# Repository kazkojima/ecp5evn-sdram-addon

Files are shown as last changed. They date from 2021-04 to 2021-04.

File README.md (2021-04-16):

# KiCAD files of a SDR ram addon for ECP5 evaluation board

KiCAD files of a simple RAM addon for Lattice LEF5UM5G-85G

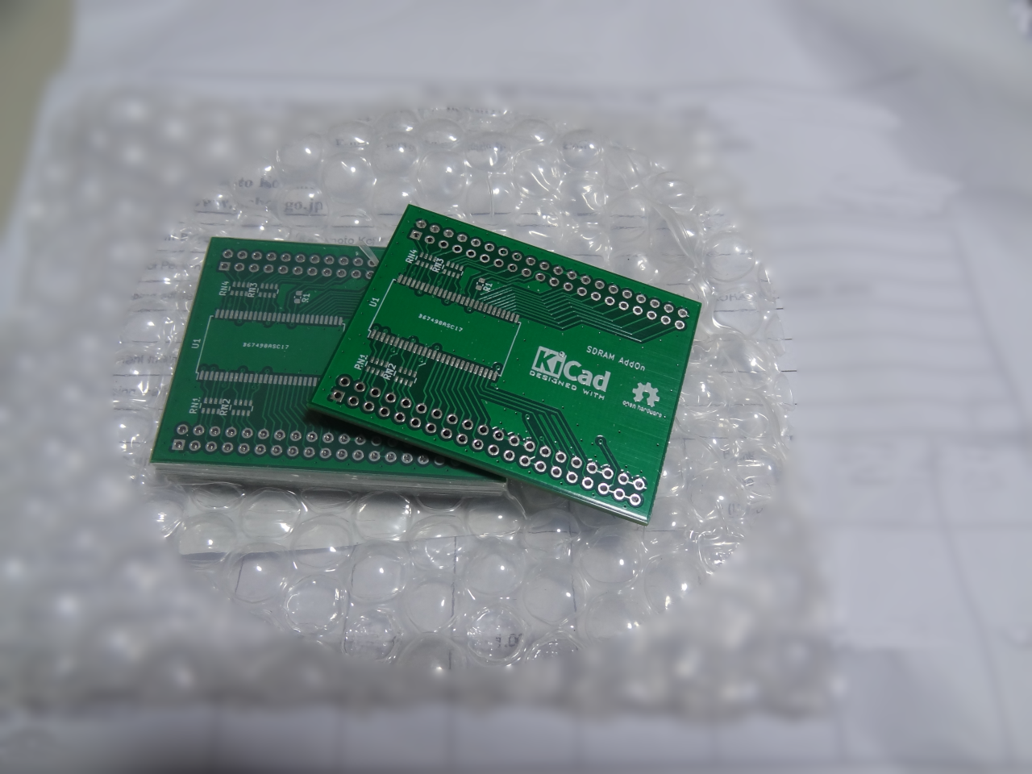
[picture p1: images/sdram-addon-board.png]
print board


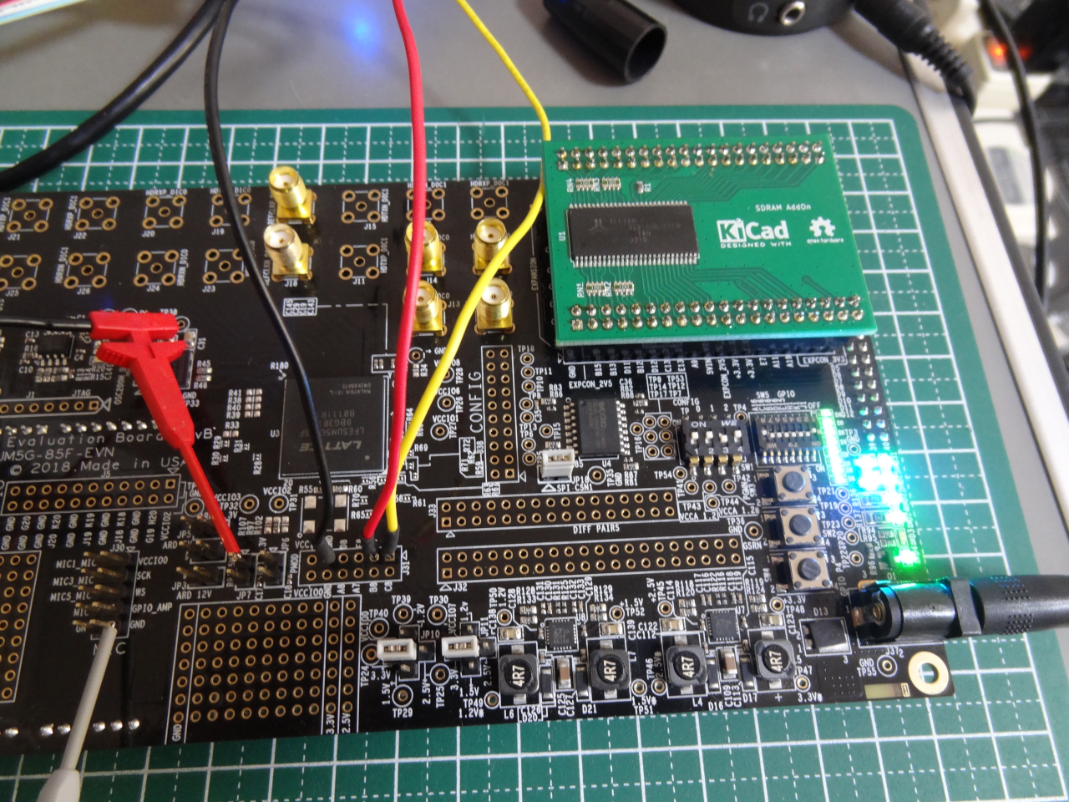
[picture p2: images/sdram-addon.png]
LEF5UM5G-85G+addon


## LiteX/[litex-boards](https://github.com/litex-hub/litex-boards.git) platform hunk of the addon

```
    # SDR SDRAM on connector J39 and J40
    ("sdram_clock", 0, Pins("K5"), IOStandard("LVCMOS33")),
    ("sdram", 0,
        Subsignal("a",     Pins(
            "B10 E7  A11 A19 K4  D14 P1  C14",
            "L1  L2  A9  N2  L3")),
        Subsignal("dq",    Pins(
            "D15 B15 C15 B13 B20 D11 E11 B12",
            "N4  M4  L4  J3  J4  H2  A15 K2")),
        Subsignal("we_n",  Pins("D12")),
        Subsignal("ras_n", Pins("C13")),
        Subsignal("cas_n", Pins("E12")),
        Subsignal("cs_n",  Pins("D13")),
        Subsignal("cke",   Pins("M5")),
        Subsignal("ba",    Pins("E13 A14")),
        Subsignal("dm",    Pins("C12 N3")),
        IOStandard("LVCMOS33"),
        Misc("SLEWRATE=FAST"),
    ),
```

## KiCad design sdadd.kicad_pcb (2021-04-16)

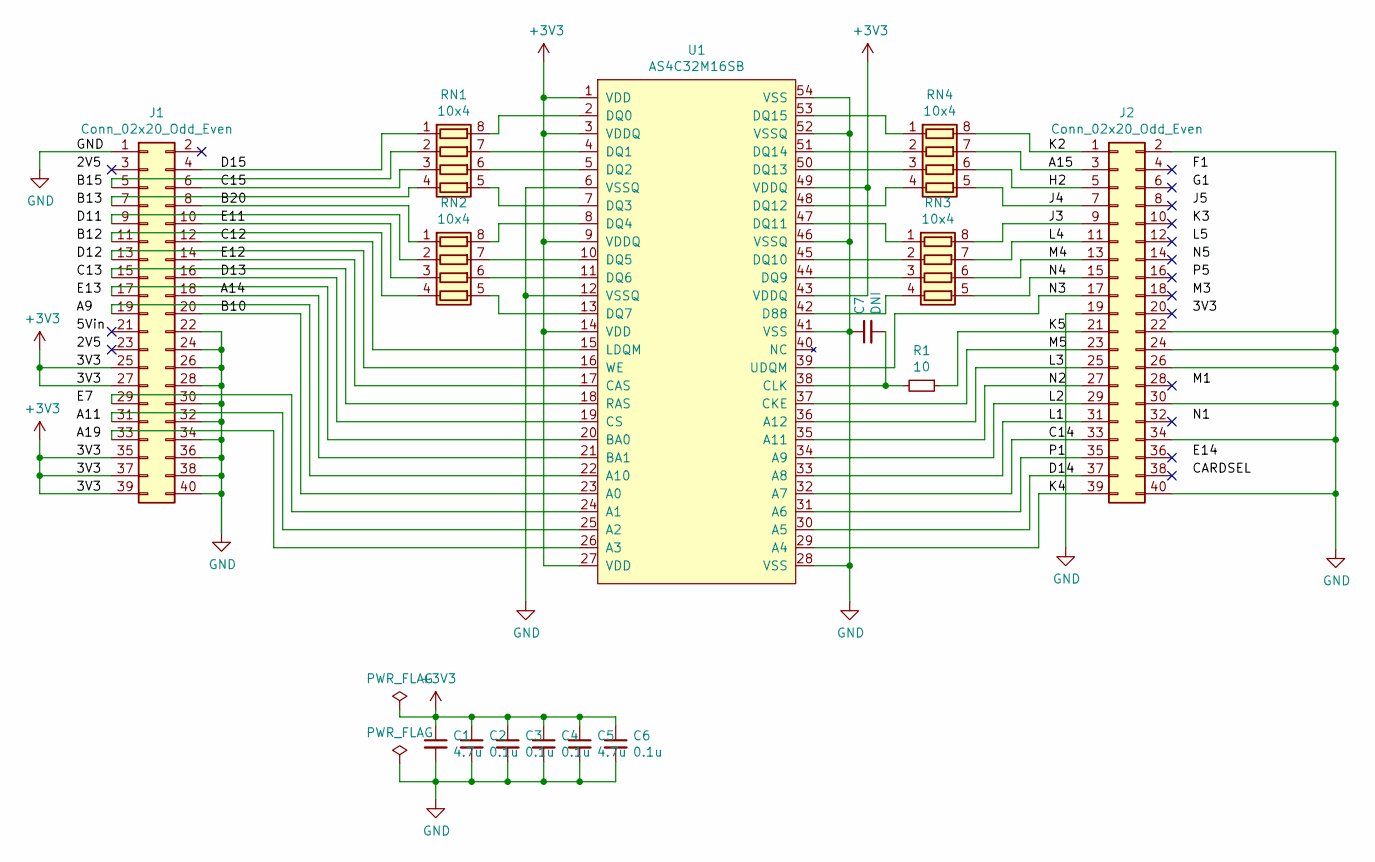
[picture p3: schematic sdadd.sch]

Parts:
C1, C5: 4.7u; C_0402_1005Metric
C2, C3, C4, C6: 0.1u; C_0402_1005Metric
C7: DNI; C_0402_1005Metric
J1, J2: Conn_02x20_Odd_Even; PinSocket_2x20_P2.54mm_Vertical
R1: 10; R_0603_1608Metric
RN1, RN2, RN3, RN4: 10x4; R_Array_Concave_4x0603
U1: AS4C32M16SB; TSOP-II-54_22.2x10.16mm_P0.8mm

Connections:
+3V3: C1.1, C2.1, C3.1, C4.1, C5.1, C6.1, J1.25, J1.27, J1.35, J1.37, J1.39, U1.1 (VDD), U1.3 (VDDQ), U1.9 (VDDQ), U1.14 (VDD), U1.27 (VDD), U1.43 (VDDQ), U1.49 (VDDQ)
/A14: J1.18, U1.21 (BA1)
/A15: J2.3, RN4.7 (R2.2)
/B10: J1.20, U1.23 (A0)
/B20: J1.8, RN2.1 (R1.1)
/C12: J1.12, U1.15 (LDQM)
/C14: J2.33, U1.32 (A7)
/C15: J1.6, RN1.3 (R3.1)
/D13: J1.16, U1.19 (CS)
/D14: J2.37, U1.30 (A5)
/D15: J1.4, RN1.1 (R1.1)
/E11: J1.10, RN2.3 (R3.1)
/E12: J1.14, U1.17 (CAS)
/H2: J2.5, RN4.6 (R3.2)
/J3: J2.9, RN3.8 (R1.2)
/J4: J2.7, RN4.5 (R4.2)
/K2: J2.1, RN4.8 (R1.2)
/K4: J2.39, U1.29 (A4)
/K5: J2.21, R1.1
/L1: J2.31, U1.33 (A8)
/L2: J2.29, U1.34 (A9)
/L3: J2.25, U1.36 (A12)
/L4: J2.11, RN3.7 (R2.2)
/M4: J2.13, RN3.6 (R3.2)
/M5: J2.23, U1.37 (CKE)
/N2: J2.27, U1.35 (A11)
/N3: J2.17, U1.39 (UDQM)
/N4: J2.15, RN3.5 (R4.2)
/P1: J2.35, U1.31 (A6)
GND: C1.2, C2.2, C3.2, C4.2, C5.2, C6.2, C7.1, J1.1, J1.22, J1.24, J1.26, J1.28, J1.30, J1.32, J1.34, J1.36, J1.38, J1.40, J2.2, J2.19, J2.22, J2.24, J2.26, J2.30, J2.34, J2.40, U1.6 (VSSQ), U1.12 (VSSQ), U1.28 (VSS), U1.41 (VSS), U1.46 (VSSQ), U1.52 (VSSQ), U1.54 (VSS)
unnamed: C7.2, R1.2, U1.38 (CLK)
unnamed: J1.5, RN1.2 (R2.1)
unnamed: J1.7, RN1.4 (R4.1)
unnamed: J1.9, RN2.2 (R2.1)
unnamed: J1.11, RN2.4 (R4.1)
unnamed: J1.13, U1.16 (WE)
unnamed: J1.15, U1.18 (RAS)
unnamed: J1.17, U1.20 (BA0)
unnamed: J1.19, U1.22 (A10)
unnamed: J1.29, U1.24 (A1)
unnamed: J1.31, U1.25 (A2)
unnamed: J1.33, U1.26 (A3)
unnamed: RN1.5 (R4.2), U1.7 (DQ3)
unnamed: RN1.6 (R3.2), U1.5 (DQ2)
unnamed: RN1.7 (R2.2), U1.4 (DQ1)
unnamed: RN1.8 (R1.2), U1.2 (DQ0)
unnamed: RN2.5 (R4.2), U1.13 (DQ7)
unnamed: RN2.6 (R3.2), U1.11 (DQ6)
unnamed: RN2.7 (R2.2), U1.10 (DQ5)
unnamed: RN2.8 (R1.2), U1.8 (DQ4)
unnamed: RN3.1 (R1.1), U1.47 (DQ11)
unnamed: RN3.2 (R2.1), U1.45 (DQ10)
unnamed: RN3.3 (R3.1), U1.44 (DQ9)
unnamed: RN3.4 (R4.1), U1.42 (D88)
unnamed: RN4.1 (R1.1), U1.53 (DQ15)
unnamed: RN4.2 (R2.1), U1.51 (DQ14)
unnamed: RN4.3 (R3.1), U1.50 (DQ13)
unnamed: RN4.4 (R4.1), U1.48 (DQ12)

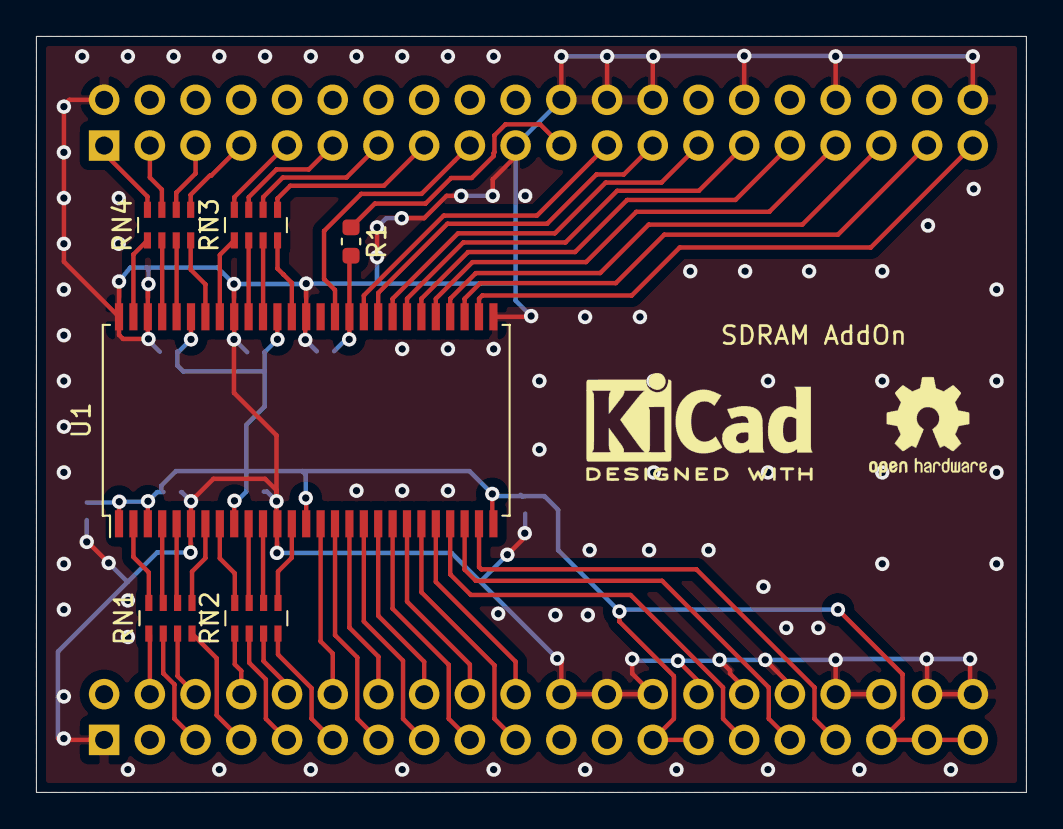
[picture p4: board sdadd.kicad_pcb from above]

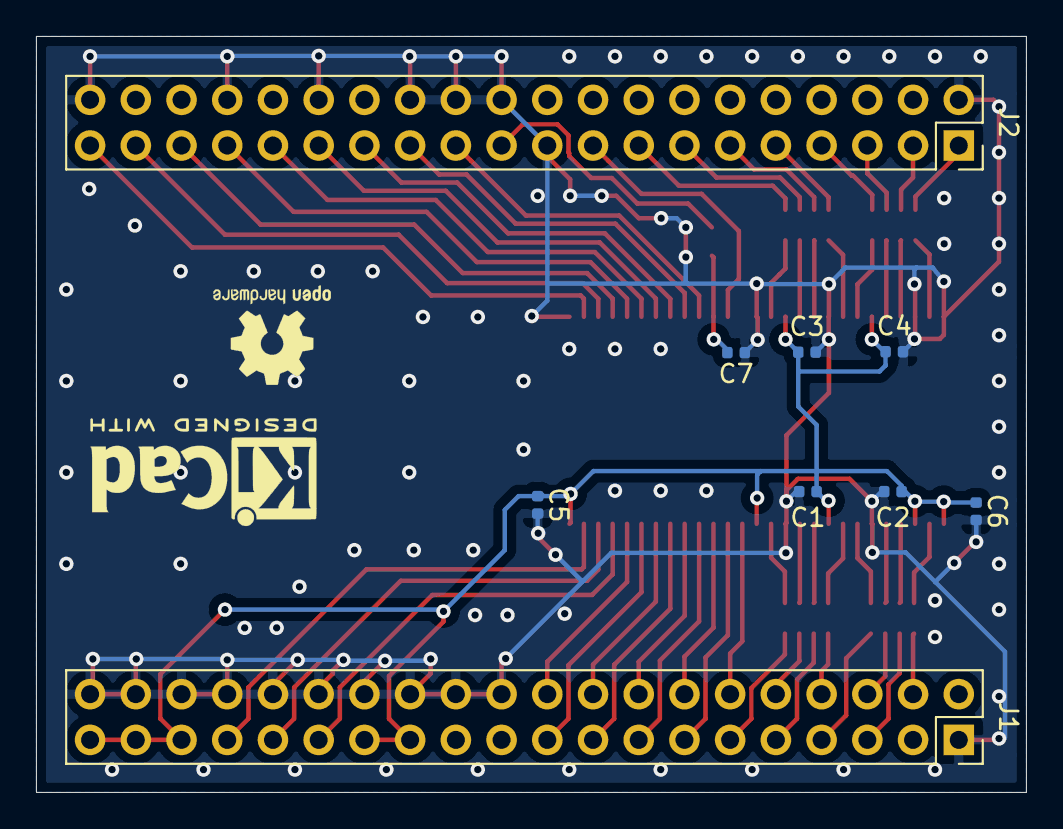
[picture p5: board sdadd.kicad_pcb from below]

Board: 2 copper layers, 55.0 x 42.0 mm, 15 parts (9 on the bottom side), 58 nets.
